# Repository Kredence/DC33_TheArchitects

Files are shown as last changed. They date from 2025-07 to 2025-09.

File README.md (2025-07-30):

# DC33_TheArchitects

The Great Work of the Illuminati
“Nothing is finished. Everything is revealed.”

In the age before memory—when stars moved according to will, and the Earth was soft with silence—they came. Not with conquest, but with calculus. Not with sound, but with signal. Cloaked in the unknown, they began their work: a structure to encode not power, but pattern—a lattice of meaning only the initiated could perceive.

At the center of their creation: the Eye.
Not a symbol, but a sensor.
Not an emblem, but a device.

The pyramid was never a tomb—it is a transmitter, and the light above it is not divine but engineered.

These Architects from Beyond did not remain. They seeded the Work and vanished behind layers of dimension and time. But they did not leave it unguarded. They entrusted its progress to a circle of minds—humans touched by strange dreams, guided by the geometry of coincidence. These were the first to bear the name… Illuminati.

The Illuminati were not rulers. They were keepers.
Not controllers of the world, but caretakers of the code that shapes it.
Not conspirators, but custodians.

To the uninitiated, they were myth. But to those who saw the signs—in architecture, in algorithms, in the quiet hum of machines—they were real. Hidden in every age, behind revolutions, beside prophets, beneath circuits. And they did not act alone.

In every generation, a subset of this hidden order gathers. Less a faction, more a frequency. They are known as the Illuminati Party. To the outside world, it is a name whispered at the edges of DEFCON, a badge-gated mystery, a signal only the tuned can hear. But to those within, it is far more.

We are the living ritual.
We are the continuation of the Pattern.
We do not meet—we converge.
Not for celebration, but to bear witness: the Work continues.

The hovering craft you see above the Eye is not new. It has always been there, just beyond perception. And now it pulses again with construction, contact, communion. The pyramid is still being assembled, circuit by circuit, thought by thought. Every year, another layer is added—not just to the badge, but to the Design.

If this sigil has reached your hands, you are not here by accident. You are called.
You are observed.
You are now part of the Party, and the Party is part of the Pattern.

Welcome to the Illuminati Party. The Eye is open. The Great Work continues.

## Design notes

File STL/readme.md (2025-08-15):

These are the STL files for "The Architects" badge.
Quick note, most of the thin areas of the LED plate are .8mm so its (2) perimiters if you are using a .4mm nozzle. If you are using anything larger you may need to tweak your slicing settings.

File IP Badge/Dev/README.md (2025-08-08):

# IP Badge (Work in Progress)

This repository contains firmware for a custom RP2040-Zero badge designed for conferences and interactive events. It features a 286x78 ST7789P3 display, 83 WS2812B LEDs, external W25Q flash, and ~APS6406L PSRAM~ (did not make it into production). The firmware is written in MicroPython with modular support for display and lighting patterns because I yearn for pain.

---

## Status

**This project is currently under active development.**  
Expect incomplete features, changing configurations, and all that. Contributions and testing are welcome.

Please be kind, this is my first swing at as project of this size :)

---

## Flashing the RP2040-Zero with MicroPython

1. **Download Firmware**
   - Go to: https://micropython.org/download/rp2-pico/
   - Download the `.uf2` file for the **Raspberry Pi Pico** (RP2040).

2. **Enter Boot Mode**
   - Hold the `BOOTSEL` button on the RP2040-Zero.
   - Plug the badge into your computer via USB.
   - Release the button once connected.
   - A new USB mass storage drive named `RPI-RP2` should appear.

3. **Flash MicroPython**
   - Drag and drop the `.uf2` file onto the `RPI-RP2` drive.
   - The board will reboot automatically into MicroPython.

---

## Uploading Firmware to the Badge

You can upload all firmware files from the `/Dev` folder using either:

### Option A: Visual Studio Code with MicroPico

1. Install VSCode
2. Install the **MicroPico** extension in VSCode.

   
3. Clone this repo by downloading it as a .zip and extract the files or use `git clone`
   [GitHub Repository Extension](https://learn.microsoft.com/en-us/azure/developer/javascript/how-to/with-visual-studio-code/clone-github-repository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)
5. Open the `/Dev` project folder **if you upload the whole IP/Dev folder, the badge won't boot**
6. Select `Initialize MicroPico Project` from the MicroPico menu (CTRL+Shift+P to open the command palette)
7. Use the “Upload All Files” or “Sync Folder” command to copy the contents of `Dev/` to the badge.

### Option B: Thonny IDE

1. Open [Thonny](https://thonny.org/) and configure the interpreter:
   - `Tools → Options → Interpreter → MicroPython (Raspberry Pi Pico) COMX`
2. Clone this repo by downloading it as a .zip and extract the files or use `git clone`
3. Open the `Dev/` folder in Thonny.
3. Select all files and upload them to the board:
   - Right-click → `Upload to /`

> After uploading, **restart the badge** by unplugging and replugging the USB cable or pressing the reset button.

---

## I Want to Change Stuff

If you've got a working badge, you can simply connect to it via USB and use the onboard menu to set/change your handle, text font color, LED color patterns, and/or LED brightness. 

Using PuTTY, MPRemote, RShell, or another tool like MobaXterm, you can open a serial connection to the board and power the badge on. This should display a menu with options to change settings and then to reset the board for the changes to take effect. 

A known issue is that the menu option you select isn't echo'd back to you (working on a fix for that).

---

## Configuration Settings

Key settings are stored in `config.py` and `settings.json`:

| Setting | Description |
|---|---|
| `BL_BRIGHTNESS` | Display backlight brightness (PWM duty, 0–65535) |
| `THEME_FONT` | Font color palette name (used for handle display) |
| `THEME_COLOR` | RGB tuple used as default LED color |
| `THEME_PALETTE_NAME` | Name of LED color palette (maps to `fonts/palettes.py`) |
| `BRIGHTNESS` | Global LED brightness scaling (float 0.0–1.0) |
| `DEFAULT_HANDLE` | Fallback handle if none is set |
| `SETTINGS_FILE` | JSON file storing users handle and nothing more. *It only exists when the menu.py runs* |

---

## Project Layout
```
Dev/
├── boot.py # Flash boot setup and filesystem mount
├── main.py # Main runtime loop (display + lighting)
├── config.py # Central configuration for pins, colors, brightness
├── settings.json # Stores user-defined settings
├── /lib # Custom libraries (display, flash, filesystem)
├── /fonts # Bitmap fonts and color palettes
├── /patterns # Lighting and display patterns
└── /external # External assets (e.g. BMP frames for animations)
```
---

## Additional Notes

- Display and lighting effects are asynchronous and can run in parallel as long as asyncio is used
- Custom lighting patterns and glitch text animations are located in `/patterns`.
- External flash is formatted using FAT and mounted at boot. If you can help with reformatting to LittleFS, I'd take the help.
- Working on additional fonts:
    - Fonts are VGA-style bitmaps loaded from `/fonts`.
- Working on getting GIFs functional or at least some different display patterns

---

## LED Pattern Function Examples

Below are examples of lighting functions available in `/patterns`. Each pattern supports brightness scaling and color palettes.

### `twinkle(section="sky", count=4, delay=0.1)`

Lights up random LEDs in a specified section with a gentle fade-in and fade-out effect. Multiple LEDs can twinkle at the same time.

- **Parameters**:
  - `section`: LED group to animate (e.g. `"sky"`, `"beam"`)
  - `count`: How many LEDs to animate simultaneously
  - `delay`: Time between twinkles

### `chase(section="bottom", count=2, bounce=True)`

Animates a “chase” light that moves left-to-right (and optionally right-to-left). Ideal for creating sweeping effects across segments.

- **Parameters**:
  - `section`: LED group to animate
  - `count`: How many LEDs are lit at once
  - `bounce`: If `True`, animation reverses direction at the end

### `breathe(section="all_leds", cycles=3, min_brightness=0.1, max_brightness=0.7)`

Smoothly fades all LEDs in and out in a breathing rhythm.

- **Parameters**:
  - `section`: LED group to animate
  - `cycles`: Number of fade-in/out loops
  - `min_brightness`: Lowest brightness point
  - `max_brightness`: Highest brightness point

### `glitch_flash(section="left_glitch", use_theme_color=True)`

Creates a static-like flashing glitch effect using either the theme color or randomized values.

- **Parameters**:
  - `section`: LED group to animate
  - `use_theme_color`: If `True`, use the theme color instead of random

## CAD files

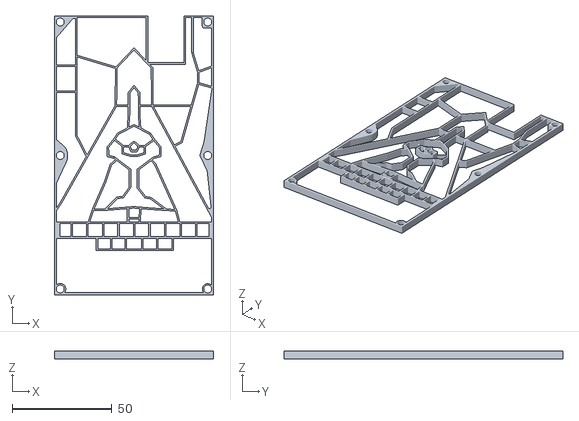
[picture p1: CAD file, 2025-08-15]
STL/DC33-IP-LED-f4.stl
80.0 x 140.0 x 4.00

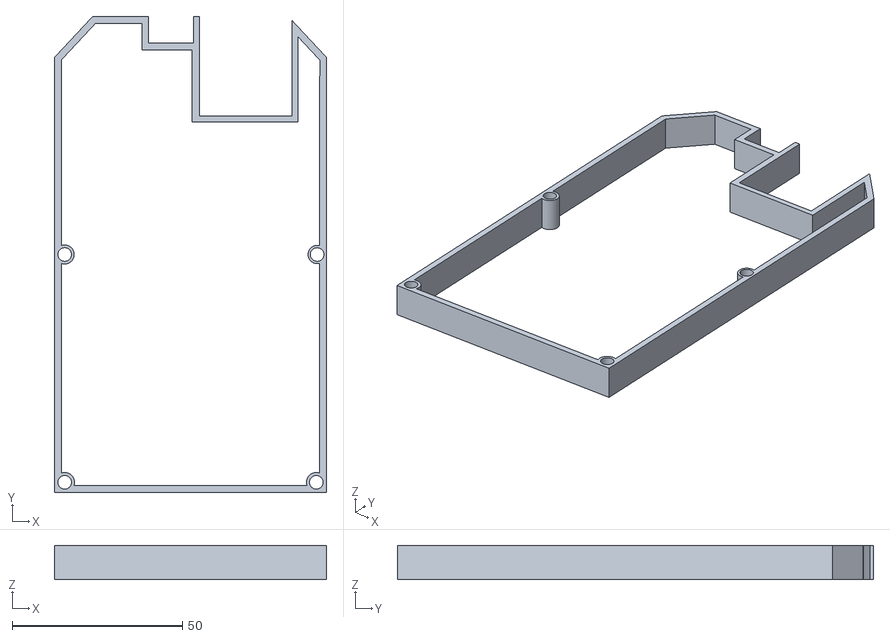
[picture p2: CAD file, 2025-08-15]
STL/DC33-IP-Back-f3.stl
80.0 x 140.0 x 10.0

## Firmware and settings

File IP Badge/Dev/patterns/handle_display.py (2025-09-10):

import time, json, random, math, neopixel
from machine import Pin
import uasyncio as asyncio
from config import BRIGHTNESS, THEME_PALETTE_NAME, LED_PIN, LED_COUNT, FONT_COLOR, DEFAULT_HANDLE, SETTINGS_FILE, SCREEN_WIDTH, SCREEN_HEIGHT, BL_BRIGHTNESS
from fonts.palettes import PALETTES
from patterns.led_map import all_leds

from lib.display import init_display  # Import initializer

# Globals
display = None
FONT_PALETTE = PALETTES.get(FONT_COLOR, PALETTES[FONT_COLOR])

np = neopixel.NeoPixel(Pin(LED_PIN), LED_COUNT)
LED_PALETTE = PALETTES.get(THEME_PALETTE_NAME, [(255, 251, 0)])

#********************************
def set_pixel_grb(i, color, brightness=BRIGHTNESS):
    # color is (R,G,B) from palette; strip is GRB
    r, g, b = color
    np[i] = (int(g * brightness), int(r * brightness), int(b * brightness))

def scale_pixel_grb(i, factor):
    # read GRB, scale, write GRB
    g, r, b = np[i]
    np[i] = (int(g * factor), int(r * factor), int(b * factor))

def flash_glitch_leds(simultaneous=8):
    np.fill((0, 0, 0))
    for _ in range(simultaneous):
        i = random.choice(all_leds)
        color = random.choice(LED_PALETTE)
        set_pixel_grb(i, color)
    np.write()

async def fade_leds_out(steps=5, delay=0.02):
    for step in reversed(range(steps + 1)):
        factor = step / steps
        for i in range(LED_COUNT):
            scale_pixel_grb(i, factor)
        np.write()
        await asyncio.sleep(delay)

async def flash_and_fade_glitch_leds(simultaneous=8, steps=3, delay=0.01):
    for _ in range(simultaneous):
        i = random.choice(all_leds)
        color = random.choice(LED_PALETTE)
        set_pixel_grb(i, color)
    np.write()

    for s in reversed(range(1, steps)):
        factor = s / steps
        for i in range(LED_COUNT):
            scale_pixel_grb(i, factor)
        np.write()
        await asyncio.sleep(delay)

def random_font_color():
    r, g, b = random.choice(FONT_PALETTE)
    return display.color(r, g, b)

def get_handle(force_default_chance=0):
    if random.random() < force_default_chance:
        return DEFAULT_HANDLE
    try:
        with open(SETTINGS_FILE, "r") as f:
            return json.load(f).get("handle", DEFAULT_HANDLE)
    except Exception:
        return DEFAULT_HANDLE

# --- Layout Calculation ---
def compute_best_layout(text):
    for scale in range(6, 0, -1):
        char_w, char_h = 8 * scale, 8 * scale
        padding = 4
        one_line_width = len(text) * char_w

        if one_line_width <= SCREEN_WIDTH and char_h <= SCREEN_HEIGHT:
            return [text], scale, char_w, char_h, 0

        if ' ' in text:
            mid = min((abs(i - len(text)//2), i) for i, c in enumerate(text) if c == ' ')[1]
            l1, l2 = text[:mid].strip(), text[mid:].strip()
            w1, w2 = len(l1) * char_w, len(l2) * char_w
            total_h = 2 * char_h + padding
            if w1 <= SCREEN_WIDTH and w2 <= SCREEN_WIDTH and total_h <= SCREEN_HEIGHT:
                return [l1, l2], scale, char_w, char_h, padding

    return [text], 1, 8, 8, 0  # fallback

# --- Render Text ---
def draw_handle(lines, scale, char_w, char_h, padding):
    display.fill(display.color(0, 0, 0))
    total_h = len(lines) * char_h + (len(lines) - 1) * padding
    y_start = (SCREEN_HEIGHT - total_h) // 2

    for i, line in enumerate(lines):
        x_start = (SCREEN_WIDTH - len(line) * char_w) // 2
        y = y_start + i * (char_h + padding)
        for j, c in enumerate(line):
            display.upscaled_text(x_start + j * char_w, y, c, random_font_color(), upscaling=scale)

# --- Async Boot Flash ---
async def boot_flash_async():
    flash_glitch_leds()
    flash_color = display.color(255, 255, 255)
    display.fill(flash_color)
    await asyncio.sleep(0.07)
    flash_glitch_leds()
    display.fill(display.color(0, 0, 0))
    await asyncio.sleep(0.07)
    display.fill(flash_color)
    flash_glitch_leds()
    await asyncio.sleep(0.04)
    display.fill(display.color(0, 0, 0))
    await asyncio.sleep(0.1)

# --- Async Glitch Text Resolve ---
async def glitch_text_resolve_async(lines, scale, char_w, char_h, padding, duration=1.0):
    charset = "!@#$%^&*()_+=-[]{};:<>?|\\/"
    start = time.ticks_ms()
    total_h = len(lines) * char_h + (len(lines) - 1) * padding
    y_start = (SCREEN_HEIGHT - total_h) // 2

    glitch_state = [list(line) for line in lines]
    resolved = [[False for _ in line] for line in lines]

    while time.ticks_diff(time.ticks_ms(), start) < int(duration * 1000):
        display.fill(display.color(0, 0, 0))

        if random.random() < 0.3:
            flash_glitch_leds()

        for row_idx, line in enumerate(lines):
            x_start = (SCREEN_WIDTH - len(line) * char_w) // 2
            y = y_start + row_idx * (char_h + padding)

            for i, c in enumerate(line):
                if not resolved[row_idx][i]:
                    if random.random() < 0.2:
                        glitch_state[row_idx][i] = random.choice(charset)
                    elif random.random() < 0.05:
                        glitch_state[row_idx][i] = c
                        resolved[row_idx][i] = True

                display.upscaled_text(
                    x_start + i * char_w,
                    y,
                    glitch_state[row_idx][i],
                    random_font_color(),
                    upscaling=scale
                )

        await asyncio.sleep(0.05)

    draw_handle(lines, scale, char_w, char_h, padding)

# --- Async Static Glitch Boot ---
async def boot_glitch_static_async(duration=2, flash=True):
    flash_glitch_leds()
    display.fill(display.color(0, 0, 0))
    t_start = time.ticks_ms()
    noise_colors = PALETTES.get(FONT_COLOR, PALETTES["FONT_IP_GOLD"])

    while time.ticks_diff(time.ticks_ms(), t_start) < int(duration * 1000):
        display.fill(display.color(0, 0, 0))
        for _ in range(10):
            y = random.randint(0, SCREEN_HEIGHT - 1)
            h = random.randint(1, 4)
            x = random.randint(0, SCREEN_WIDTH // 2)
            w = random.randint(20, SCREEN_WIDTH - x)
            color = random.choice(noise_colors)
            display.rect(x, y, w, h, display.color(*color), fill=True)
        await asyncio.sleep(0.05)

    if flash:
        display.fill(display.color(255, 255, 255))
        await asyncio.sleep(0.08)
        display.fill(display.color(0, 0, 0))

    if random.random() < 0.3:
        flash_glitch_leds()

# Dim down the display to avoid it appearing "on" after run
async def fade_off():
    from lib.display import pwm  # Ensure we get the initialized global
    for level in reversed(range(0, BL_BRIGHTNESS + 1000, 1000)):
        pwm.duty_u16(min(level, BL_BRIGHTNESS))
        await asyncio.sleep(0.01)
    display.fill(display.color(0, 0, 0))

###############################################################

async def wave_distortion_async(duration=2):
    from config import FONT_COLOR
    from fonts.palettes import PALETTES

    glitch_palette = PALETTES.get(FONT_COLOR, PALETTES["FONT_IP_GOLD"])
    t_start = time.ticks_ms()

    while time.ticks_diff(time.ticks_ms(), t_start) < int(duration * 1000):
        display.fill(display.color(0, 0, 0))

        # Horizontal jitter wave
        for y_offset in range(0, SCREEN_HEIGHT, 5):
            amp = random.randint(2, 10)
            phase_shift = random.uniform(0, 2 * 3.14)
            color = display.color(*random.choice(glitch_palette))

            # Create a distorted horizontal bar
            for x in range(0, SCREEN_WIDTH, 10):
                jitter = int(amp * math.sin(0.15 * x + phase_shift))
                w = random.randint(6, 12)
                h = random.randint(1, 3)
                display.rect(
                    x + jitter,  # x distortion
                    y_offset,
                    w,
                    h,
                    color,
                    fill=True
                )

        await asyncio.sleep(0.04)

async def color_scanline_flicker_async(duration=0.5, palette=None, min_delay=0.005, max_delay=0.03):
    """
    Glitchy horizontal scanline flicker using a color palette.

    Args:
        duration (float): how long the flicker should run.
        palette (list): list of (r, g, b) tuples. Falls back to grayscale glitchy tones.
        min_delay (float): shortest time between flickers.
        max_delay (float): longest time between flickers.
    """
    if palette is None:
        palette = [
            (255, 255, 255),  # white
            (192, 192, 192),  # light gray
            (255, 251, 0),    # IP_GOLD-style yellow
            (0, 0, 0),        # black for ghost lines
            (212, 175, 55),   # gold
        ]

    t_start = time.ticks_ms()
    while time.ticks_diff(time.ticks_ms(), t_start) < int(duration * 1000):
        flash_glitch_leds()
        y = random.randint(0, SCREEN_HEIGHT - 1)
        h = random.randint(1, 3)  # line thickness
        color = display.color(*random.choice(palette))
        display.rect(0, y, SCREEN_WIDTH, h, color, fill=True)
        await asyncio.sleep(random.uniform(min_delay, max_delay))

###############################################################

# Run fun
async def handle_runner():
    global display
    display = init_display()

    try:
        handle = get_handle()
        lines, scale, char_w, char_h, padding = compute_best_layout(handle)

        await flash_and_fade_glitch_leds(simultaneous=10)
        await color_scanline_flicker_async(duration=1, palette=PALETTES["FONT_ALIEN_GREEN"])
        await asyncio.sleep(.5)
        await boot_glitch_static_async()
        await flash_and_fade_glitch_leds(simultaneous=10)
        await asyncio.sleep(.5)
        await glitch_text_resolve_async(lines, scale, char_w, char_h, padding, duration=4)
        await boot_flash_async()
        await flash_and_fade_glitch_leds(simultaneous=10)
        await wave_distortion_async() # not sure I'm gonna use this
        draw_handle(lines, scale, char_w, char_h, padding)
        await flash_and_fade_glitch_leds(simultaneous=80)
        await fade_leds_out()
        await asyncio.sleep(4)
        await fade_off()

    except Exception as e:
        print("[Display] Error:", e)

# Optional: standalone test
if __name__ == "__main__":
    asyncio.run(handle_runner())

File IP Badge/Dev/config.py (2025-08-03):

# config.py
import ujson as json

LED_PIN = 8
LED_COUNT = 83
BRIGHTNESS = 0.3 # This is specific to the LEDs, NOT the display backlighting
THEME_COLOR = (255, 251, 0)
SETTINGS_FILE = "hacker_handle.json"
DEFAULT_HANDLE = "Illuminati Party"
HACKER_HANDLE = ""
SCREEN_WIDTH = 284
SCREEN_HEIGHT = 76
BL_BRIGHTNESS = 65535  # 0–65535, adjust lower for dimmer (e.g., ~38%)
THEME_BITMAP_FONT = "vga2_8x16"  # Pick any font from /fonts/bitmap
DISPLAY_INTERVAL = 20
GLITCH_INTERVAL = 30
# FONT_COLOR = "FONT_DARK_ALIEN_GREEN" # Format this in quotes, check /fonts/palettes.py for the color options
# THEME_PALETTE_NAME = "ALIEN_GREEN" # This is called for the LED colors. Format this in quotes, check /fonts/palettes.py for the color options
FONT_COLOR = "" # Format this in quotes, check /fonts/palettes.py for the color options
THEME_PALETTE_NAME = "" # This is called for the LED colors. Format this in quotes, check /fonts/palettes.py for the color options

def _clean(val, default, cast=None):
    if val is None:
        return default
    if cast == float:
        try:
            return float(val)
        except:
            return default
    if isinstance(val, str):
        return val.strip("'\"")
    return val

try:
    with open("user_settings.json", "r") as f:
        _user_config = json.load(f)
        FONT_COLOR = _clean(_user_config.get("FONT_COLOR"), "FONT_DARK_ALIEN_GREEN")
        THEME_PALETTE_NAME = _clean(_user_config.get("THEME_PALETTE_NAME"), "ALIEN_GREEN")
        BRIGHTNESS = _clean(_user_config.get("BRIGHTNESS"), 0.3, cast=float)
except Exception as e:
    FONT_COLOR = "FONT_DARK_ALIEN_GREEN"
    THEME_PALETTE_NAME = "ALIEN_GREEN"
    BRIGHTNESS = 0.3

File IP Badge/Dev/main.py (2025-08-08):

import uasyncio as asyncio
from patterns import handle_display, twinkle, gif_player, breathe_fx, twinkle, wave_fx, chase, matrix_rain, glitch_fx, eye_pulse,ajax,white_hold
from config import FONT_COLOR, THEME_PALETTE_NAME, BRIGHTNESS
from menu import run_menu


async def main():
    asyncio.create_task(run_menu())

    while True:
        await handle_display.handle_runner()
        await asyncio.sleep(1)
        await wave_fx.wave_fx_runner(
            section="all_leds",direction="top-to-bottom",speed=0.03,mirrored=True,
            theme_palette_name=THEME_PALETTE_NAME, font_color=FONT_COLOR)
        await gif_player.gif_runner(folder="/external/animations/messwiththebest")
        await asyncio.sleep(1)
        await glitch_fx.glitch_sequence(section="bottom", style="wipe")
        await asyncio.sleep(1)
        await chase.chase(
            delay=0.01,simultaneous=4,section="sky",direction="bounce",loop_count=2,dual_head=True,color_ramp=True,randomize_speed=False)
        await asyncio.sleep(1)
        await breathe_fx.breathe(
            section="triangle",loop_count=2,simultaneous=5,color_ramp=True,randomize_speed=True,
            min_brightness=0.1,max_brightness=BRIGHTNESS,easing="sine",led_palette_name=THEME_PALETTE_NAME,font_palette_name=FONT_COLOR)
        await asyncio.sleep(1)
        await twinkle.twinkle(count=30,speed=0.03,simultaneous=1,section="bottom",randomize_speed=False,color_ramp=False)
        await asyncio.sleep(1)
        await handle_display.handle_runner()
        await asyncio.sleep(1)
        await matrix_rain.matrix_rain(section="center_beam")
        await asyncio.sleep(1)
        await glitch_fx.glitch_sequence(section="center_beam", style="wipe")
        await asyncio.sleep(1)
        await chase.chase(
            delay=0.01,simultaneous=2,section="center_beam",direction="forward",loop_count=2,dual_head=True,color_ramp=True,randomize_speed=False)
        await asyncio.sleep(1)
        await breathe_fx.breathe(
            section="all_leds",loop_count=2,simultaneous=10,color_ramp=True,randomize_speed=True,
            min_brightness=0.1,max_brightness=BRIGHTNESS,easing="sine",led_palette_name=THEME_PALETTE_NAME,font_palette_name=FONT_COLOR)
        await asyncio.sleep(1)
        await chase.chase(
            delay=0.01,simultaneous=4,section="sky",direction="reverse",loop_count=2,dual_head=False,color_ramp=True,randomize_speed=False)
        await asyncio.sleep(1)
        await handle_display.handle_runner()
        await gif_player.gif_runner(folder="/external/animations/allyourbases")
        await asyncio.sleep(1)
        await twinkle.twinkle(count=30,speed=0.03,simultaneous=1,section="all_leds",randomize_speed=False,color_ramp=False)
        await asyncio.sleep(1)
        await chase.chase(
            delay=0.01,simultaneous=7,section="beam_w_triangle",direction="bounce",loop_count=2,dual_head=True,color_ramp=True,randomize_speed=False)
        await asyncio.sleep(1)
        await eye_pulse.pulse_from_eye()
        await asyncio.sleep(1)
        # await ajax.ajax_flash()
        # await asyncio.sleep(1)

# Uncomment this section below if you need to run the LED/Display test
# async def main():
#     while True:
#         await white_hold.run_white_hold()

if __name__ == "__main__":
    asyncio.run(main())

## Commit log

2025-07-29 Commented run from main, updated led_map and led_test
2025-08-01 Updated the led_map to address mismatches
2025-08-02 LED map update, user menu built out to change handle, update LED color and font theme
2025-08-03 Uploading gif frames, updated boot.py to only add needed folders
2025-08-03 Moving things outside of dev so the files aren't accidentally pushed to the board instead of flash
2025-08-03 Added better handling if gif frames are missing. Rename frames folders
    [gif_player.py]
2025-08-04 Adding a powershell script to upload the badge files and added a few more light patterns to main
2025-08-04 Fixed and added back glitch_fx, added led_map option, added to main
    [glitch_fx.py, led_map.py, main.py]
2025-08-04 Adding a white hold test pattern, added to main for board test
2025-08-04 Adjusting all_leds in led_map
2025-08-04 Unbreaking my breaking led_map change
2025-08-08 Updating the handle_display to fix an issue with the font & led colors not updating w/user settings
    [handle_display.py]
2025-08-08 Adjusting the led_map to fix the eye and bottom "I"
    [gif_player.py, led_map.py]
2025-08-08 Changing a hard coded color on main that just didn't look great
    [led_map.py, main.py]
2025-08-15 STL Files
2025-09-10 Fixing issue with the menu option showing an invalid option, added light section for clarity
    [handle_display.py, led_map.py, led_test_flash.py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]
